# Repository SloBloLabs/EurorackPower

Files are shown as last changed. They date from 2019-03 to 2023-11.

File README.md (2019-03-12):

# EurorackPower

A(nother) power distribution board, mainly intended to learn about the PCB design an manufacturing process.

Here is the [BOM] with mouser references.

## Features

 * Using 1,4mm traces, enough to process 3A on 1oz PCB
 * Additional capacitors on board per power line to counter ripple and noise
 * Onboard jumper to normalize 0V to earth ground
 * Dashed silkscreen lines to safely cut the PCB if less than 3 rows/connectors are actually needed for the application
 * Open Source Hardware

## Images

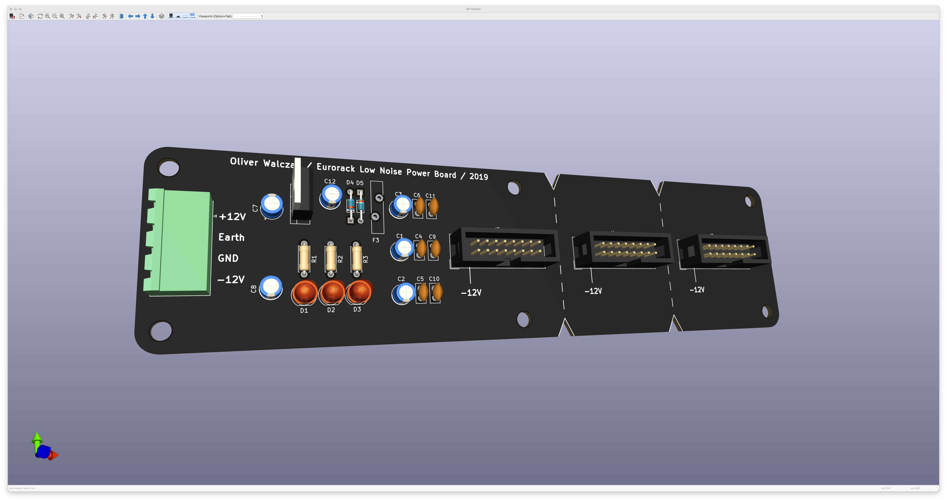
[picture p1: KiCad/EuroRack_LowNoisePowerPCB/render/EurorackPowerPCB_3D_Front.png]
Eurorack Power PCB, Front View


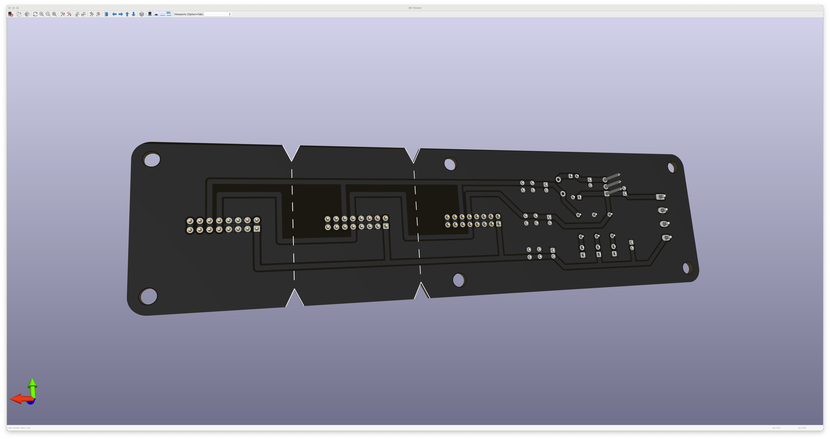
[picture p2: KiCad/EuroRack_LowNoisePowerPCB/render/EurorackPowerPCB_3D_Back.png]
Eurorack Power PCB, Rear View


## Additional Info

This open hardware project needs an external +12V, 0V, -12V power supply.

Please find the [Wiring] schematic for further details.

Watch the related [video] on Youtube for an in depth tutorial.

DIY Eurorack Case (https://www.youtube.com/watch?v=7tzhh7atj4o)

[BOM]: EurorackPowerBOM_2019-03-02.xlsx
[Wiring]: KiCad/Wiring/Wiring.pdf
[video]: https://youtu.be/7tzhh7atj4o

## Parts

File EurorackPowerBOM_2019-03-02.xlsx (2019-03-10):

Qty | Parts | Value | Device | Package | Mouser Ref# | Description | New Project
3 | C9,C10,C11 | 1pF | Capacitor THT | Radial | 810-FA18C0G1H01000 | Multilayer Ceramic Capacitors MLCC - Leaded 50V 1pF C0G RAD LS:2.5mm AEC-Q200 | 3
3 | C4,C5,C6 | 1nF | Capacitor THT | Radial | 80-C315C102J3G5TA | Multilayer Ceramic Capacitors MLCC - Leaded | 3
6 | C1,C2,C3,C7,C8,C12 | 1uF | Capacitor THT | Radial | 710-860020672005 | Aluminium Electrolytic Capacitors - Radial Leaded WCAP-ATG5 50V 1uF 20% ESR=39554mOhms | 6
1 | D1 | red | LED THT | 5mm | 941-C503BRANCZ0C0AA1 | Standard LEDs - Through Hole Red Round | 1
1 | D2 | blue | LED THT | 5mm | 941-C503BBANCY0C0461 | Standard LEDs - Through Hole Blue Round LED | 1
1 | D3 | green | LED THT | 5mm | 941-C503BGCNCY0C0791 | Standard LEDs - Through Hole Green Round LED | 1
2 | D4,D5 | 1N4002 | Diode, Rectifier | DO-41 | 833-1N4002-TP | Rectifiers Vr/100V Io/1A | 2
3 | F1,F2,F3 |  | PTC THT | Radial | 652-MF-RX160/72-0 | Resettable Fuses - PPTC 1.60A 72V 0.09ohm Hold 1.6 Trip 3.2 | 3
1 | J1 | MSTBA_2,5_HC/_4-G-5,08 | THT |  | 651-1923885 | Pluggable Terminal Blocks 4 Pos 5.08mm pitch Through Hole Header | 1
1 | for J1 | MSTB_2,5_HC/_4-ST-5,08 |  |  | 651-1911981 | Pluggable Terminal Blocks 4 Pos 5.08mm pitch Plug 24-12 AWG Screw | 1
1 | J2 |  | THT |  | 649-68797-403HLF | Headers & Wire Housings BRKAWY HDR STR SR 1X03 100/213 | 1
1 | for J2 | SNT-100-BK-T | THT |  | 200-SNT100BKT | Headers & Wire Housings Shunt | 1
3 | J3,J4,J5 |  | THT |  | 538-70246-1601 | Headers & Wire Housings 16CKT SHRD HDR | 3
2 | R1,R2 | 10k | THT | Axial | 603-CFR-25JR-5210K | Carbon Film Resistors 10K ohm 1/4W 5% | 2
1 | R3 | 1k | THT | Axial | 603-CFR-25JR-521K | Carbon Film Resistors - Through Hole 1K ohm 1/4W 5% | 1
1 | U1 | UA7805CK | Linear Voltage Regulator, THT | TO-220-3 | 595-UA7805CKCT | Linear Voltage Regulators 3P 1.5A Fixed 5V Pos Vltg Reg | 1
1 | for U1 |  | TO-220 Heat Sink | TO-220 | 532-576802B00 | Heat Sinks Plug-In Style Heatsink for TO-220, Four Spring Action Clips, Slim, Vertical Mounting, 27.3 n Thermal Resistance, Black Anodized, No Mounting Tab | 1
2 | Switched Power Supply | 12V | Switched Power Supply 36W 12V 3A |  | 709-LRS35-12 | Switched Power Supply 36W 12V 3A | 2
 | New Project QTY | 1

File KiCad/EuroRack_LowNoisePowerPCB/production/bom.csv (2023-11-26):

Designator | Footprint | Quantity | Value | LCSC Part #
C1, C12, C2, C3, C7, C8 | CP_Radial_D5.0mm_P2.00mm | 6 | 1uF
C10, C11, C9 | C_Disc_D5.0mm_W2.5mm_P2.50mm | 3 | 1pF
C4, C5, C6 | C_Disc_D5.0mm_W2.5mm_P2.50mm | 3 | 1nF
D1 | LED_D5.0mm | 1 | red
D2 | LED_D5.0mm | 1 | blue
D3 | LED_D5.0mm | 1 | green
D4, D5 | D_DO-34_SOD68_P7.62mm_Horizontal | 2 | 1N4007
F3 | Fuse_Bourns_MF-RG900 | 1 | MF-RX160/72-0
H1, H2, H3, H4, H5, H6 | MountingHole_4.3mm_M4 | 6 | MountingHole
J1 | PhoenixContact_MSTBA_2,5_4-G-5,08_1x04_P5.08mm_Horizontal | 1 | Conn_01x04
J3, J4, J5 | IDC-Header_2x08_P2.54mm_Vertical | 3 | Conn_02x08_Odd_Even
R1, R2 | R_Axial_DIN0207_L6.3mm_D2.5mm_P7.62mm_Horizontal | 2 | 10K
R3 | R_Axial_DIN0207_L6.3mm_D2.5mm_P7.62mm_Horizontal | 1 | 1K
U1 | TO-220-3_Vertical | 1 | LM7805_TO220

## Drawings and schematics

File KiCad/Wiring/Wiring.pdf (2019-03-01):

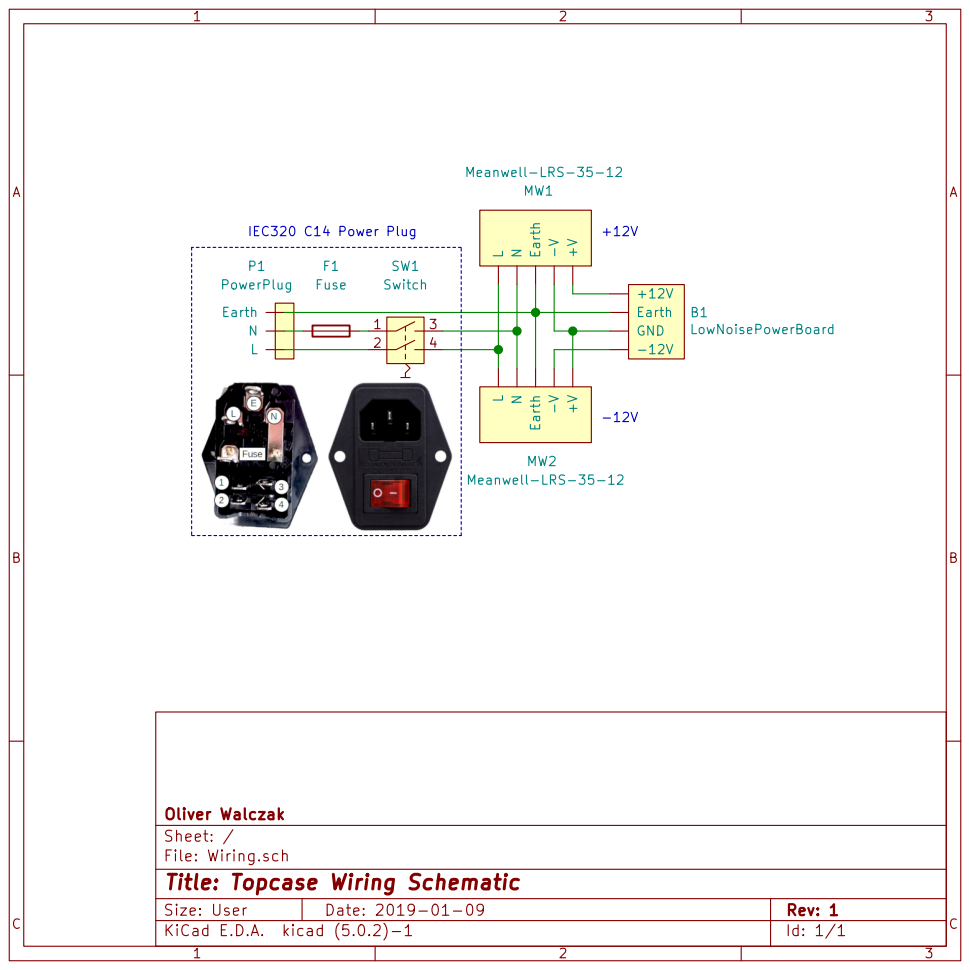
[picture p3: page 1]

File: Wiring.sch Sheet: / Oliver Walczak

Id: 1/1 Title: Topcase Wiring Schematic

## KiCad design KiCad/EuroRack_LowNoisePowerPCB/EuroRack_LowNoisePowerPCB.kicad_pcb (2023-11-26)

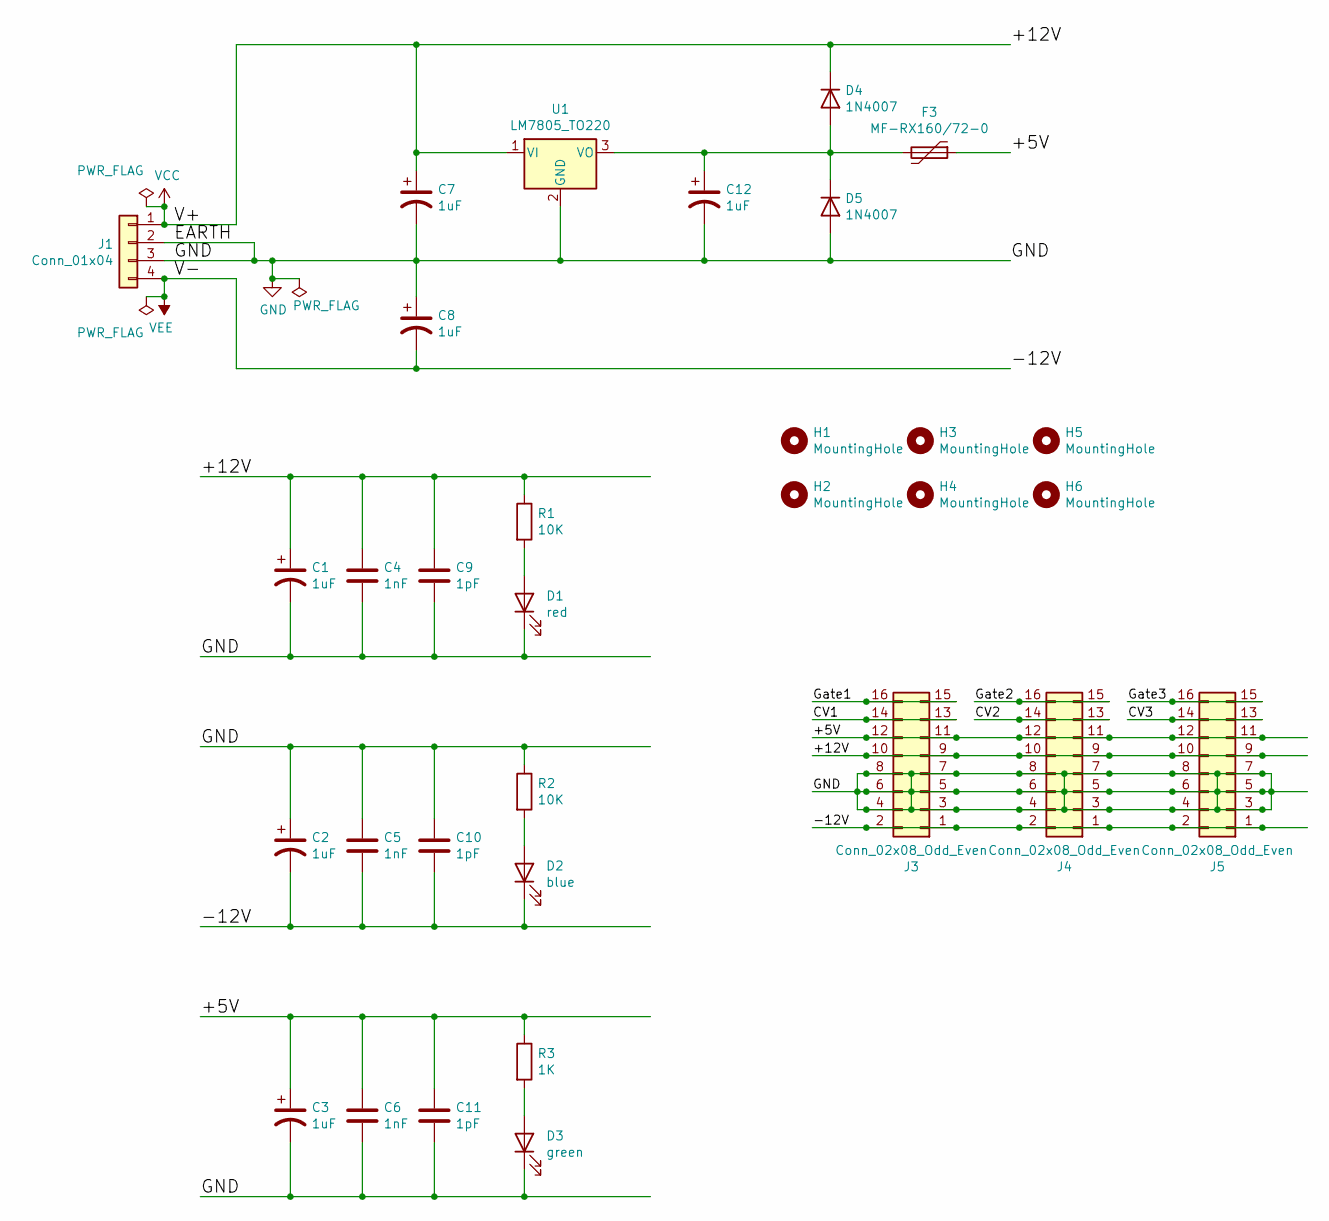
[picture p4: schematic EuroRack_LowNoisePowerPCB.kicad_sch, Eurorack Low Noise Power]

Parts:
C1, C2, C3, C7, C8, C12: 1uF; CP_Radial_D5.0mm_P2.00mm
C4, C5, C6: 1nF; C_Disc_D5.0mm_W2.5mm_P2.50mm
C9, C10, C11: 1pF; C_Disc_D5.0mm_W2.5mm_P2.50mm
D1: red; LED_D5.0mm
D2: blue; LED_D5.0mm
D3: green; LED_D5.0mm
D4, D5: 1N4007; D_DO-34_SOD68_P7.62mm_Horizontal
F3: MF-RX160/72-0; Fuse_Bourns_MF-RG900
H1, H2, H3, H4, H5, H6: MountingHole; MountingHole_4.3mm_M4
J1: Conn_01x04; PhoenixContact_MSTBA_2,5_4-G-5,08_1x04_P5.08mm_Horizontal
J3, J4, J5: Conn_02x08_Odd_Even; IDC-Header_2x08_P2.54mm_Vertical
R1, R2: 10K; R_Axial_DIN0207_L6.3mm_D2.5mm_P7.62mm_Horizontal
R3: 1K; R_Axial_DIN0207_L6.3mm_D2.5mm_P7.62mm_Horizontal
U1: LM7805_TO220; TO-220-3_Vertical

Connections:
/+5V: C3.1, C6.1, C11.1, F3.1, J3.11, J3.12, J4.11, J4.12, J5.11, J5.12, R3.1
/CV1: J3.13, J3.14
/CV2: J4.13, J4.14
/CV3: J5.13, J5.14
/Gate1: J3.15, J3.16
/Gate2: J4.15, J4.16
/Gate3: J5.15, J5.16
GND: C1.2, C2.1, C3.2, C4.2, C5.1, C6.2, C7.2, C8.1, C9.2, C10.1, C11.2, C12.2, D1.1 (K), D3.1 (K), D5.2 (A), J1.2, J1.3, J3.3, J3.4, J3.5, J3.6, J3.7, J3.8, J4.3, J4.4, J4.5, J4.6, J4.7, J4.8, J5.3, J5.4, J5.5, J5.6, J5.7, J5.8, R2.1, U1.2 (GND)
unnamed: D1.2 (A), R1.2
unnamed: D2.2 (A), R2.2
unnamed: D3.2 (A), R3.2
unnamed: C12.1, D4.2 (A), D5.1 (K), F3.2, U1.3 (VO)
VCC: C1.1, C4.1, C7.1, C9.1, D4.1 (K), J1.1, J3.9, J3.10, J4.9, J4.10, J5.9, J5.10, R1.1, U1.1 (VI)
VEE: C2.2, C5.2, C8.2, C10.2, D2.1 (K), J1.4, J3.1, J3.2, J4.1, J4.2, J5.1, J5.2

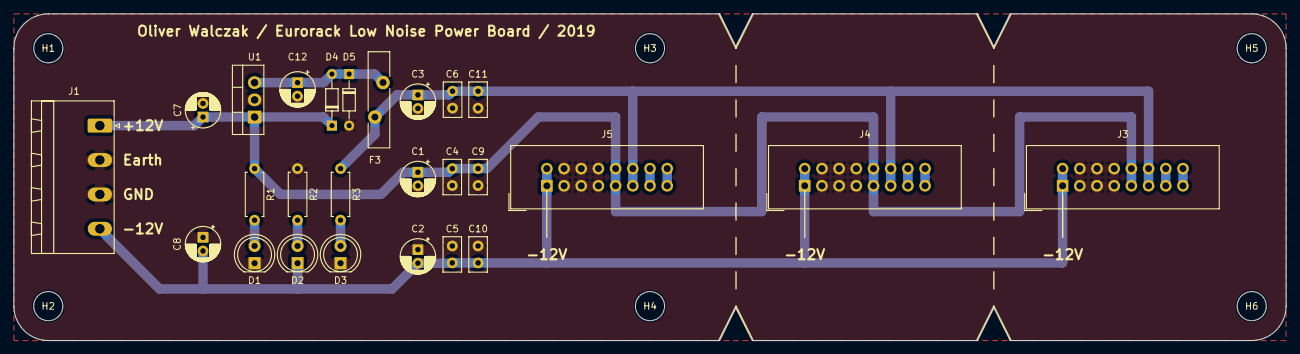
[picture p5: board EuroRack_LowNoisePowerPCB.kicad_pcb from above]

Board: 2 copper layers, 188.0 x 48.3 mm, 32 parts (0 on the bottom side), 14 nets.

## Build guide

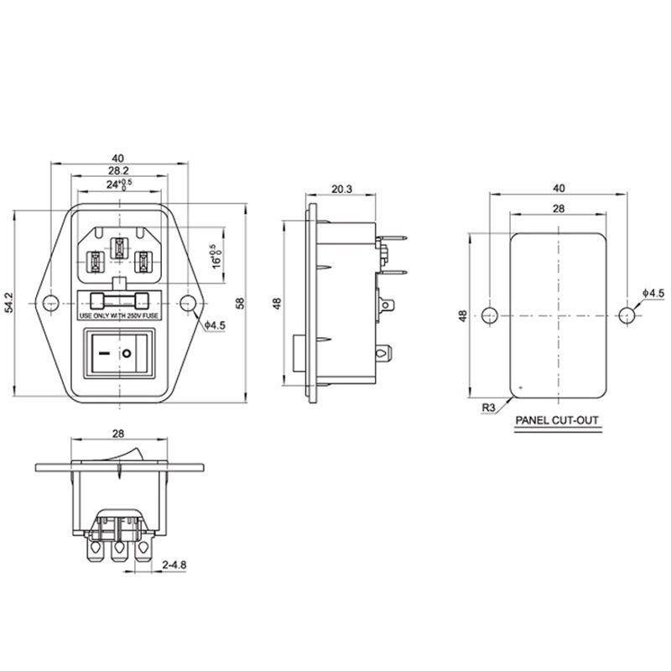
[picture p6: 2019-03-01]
KiCad/Wiring/resources/a6a198ff339d3c81dbf97baca741cad0.jpg

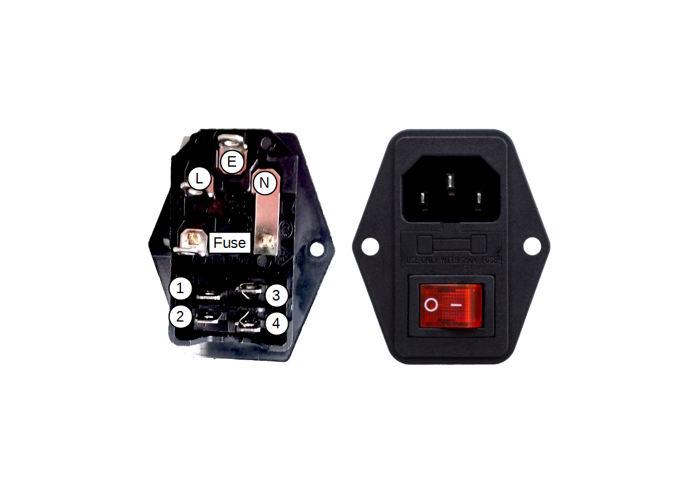
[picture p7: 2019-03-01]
KiCad/Wiring/resources/C14PowerPlug_Annotated_Large.bmp

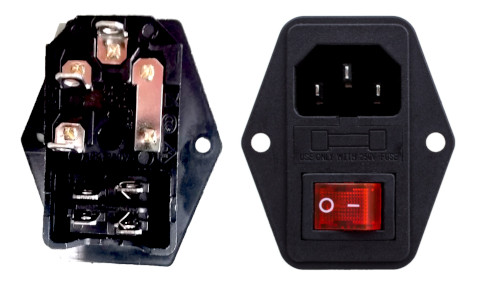
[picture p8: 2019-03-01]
KiCad/Wiring/resources/C14PowerPlug_Small.jpg

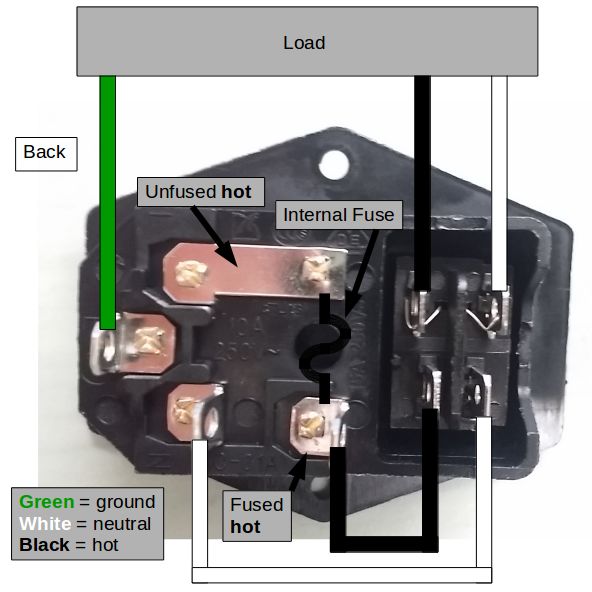
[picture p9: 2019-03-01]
KiCad/Wiring/resources/FPQ022KIYB2EI0Z.LARGE.jpg

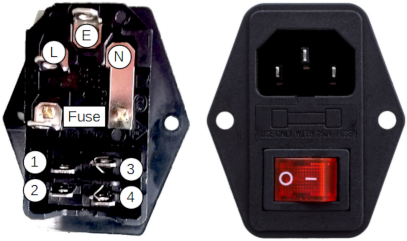
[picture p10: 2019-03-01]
KiCad/Wiring/resources/C14PowerPlug_Annotated_Small.bmp

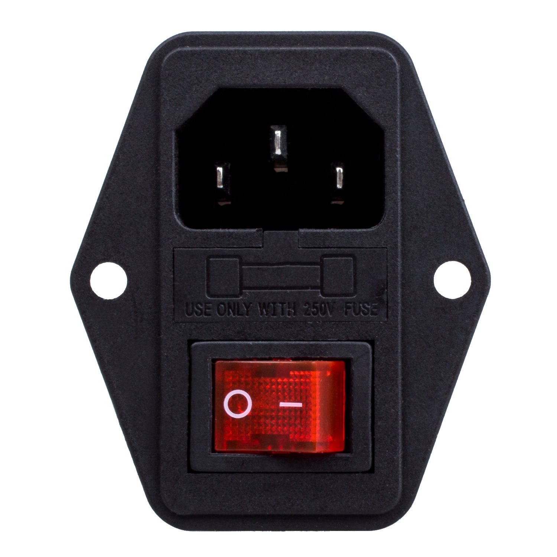
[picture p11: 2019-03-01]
KiCad/Wiring/resources/CNIM-Hot-3-Pin-IEC320-C14-Inlet-Module-Plug-Fuse-Switch-Male-Power-Socket-10A-250V.jpg

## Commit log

2019-03-01 initial upload of KiCad Low Noice Power PCD
    [EuroRack_LowNoisePowerPCB-B.Cu.gbr, EuroRack_LowNoisePowerPCB-B.Mask.gbr, EuroRack_LowNoisePowerPCB-B.SilkS.gbr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]
2019-03-01 Add wiring schematic
    [Wiring.sch]
2019-03-01 Move wiring schematic to KiCad folder
    [Wiring.sch]
2019-03-01 Rearrangement of wiring subfolders
    [Wiring.sch]
2019-03-10 Screenshots added BOM updated Readme updated
    [EurorackPowerBOM_2019-03-02.xlsx]
2023-11-26 Migrate to KiCad 7 Remove PTC and remove grounding option
    [EuroRack_LowNoisePowerPCB-B.Cu.gbr, EuroRack_LowNoisePowerPCB-B.Mask.gbr, EuroRack_LowNoisePowerPCB-B.SilkS.gbr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]
